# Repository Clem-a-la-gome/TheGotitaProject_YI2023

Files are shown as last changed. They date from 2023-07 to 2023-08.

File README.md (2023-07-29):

# The Gotita Project - Young Innovators 2023

This repository has been made in the context of the Young Innovator scholarship of 2023 granted by the Colombian Ministry of Science. Our ambition is to create a water quality monitoring system for rural isolated zones.

<p align="center">
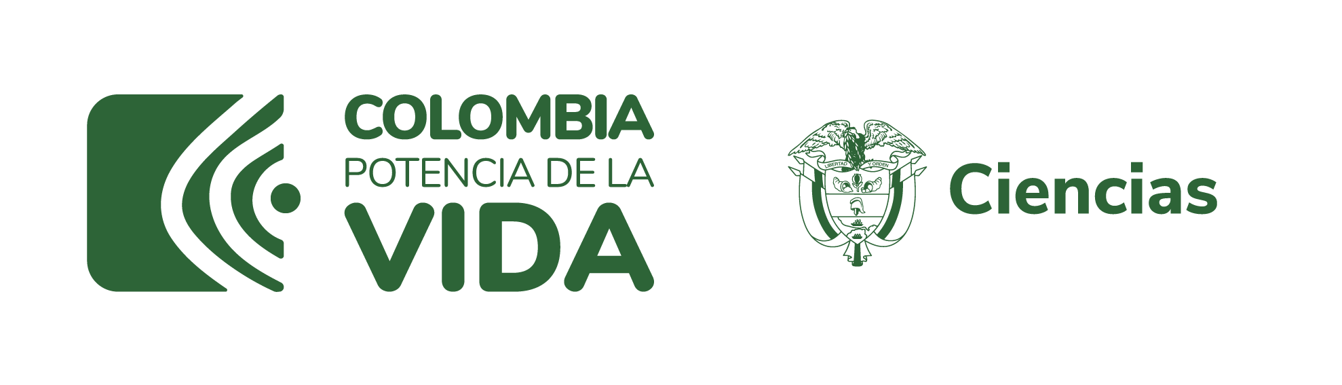
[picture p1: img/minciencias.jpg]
  
</p>

## Problem Statement

In 2017, an estimated 1.2 million people died due to unsafe water sources. This was 2.2% of global deaths. More particularly, In Colombia, there is a severe problem with access to drinking water in rural areas, where the supply doesn't exceed 35%. In addition, in 2020 approximately 884,545 cases of Acute Diarrheal Disease (ADD) were estimated. This disease is highly related to the consumption of water of poor quality.

<p align="center">
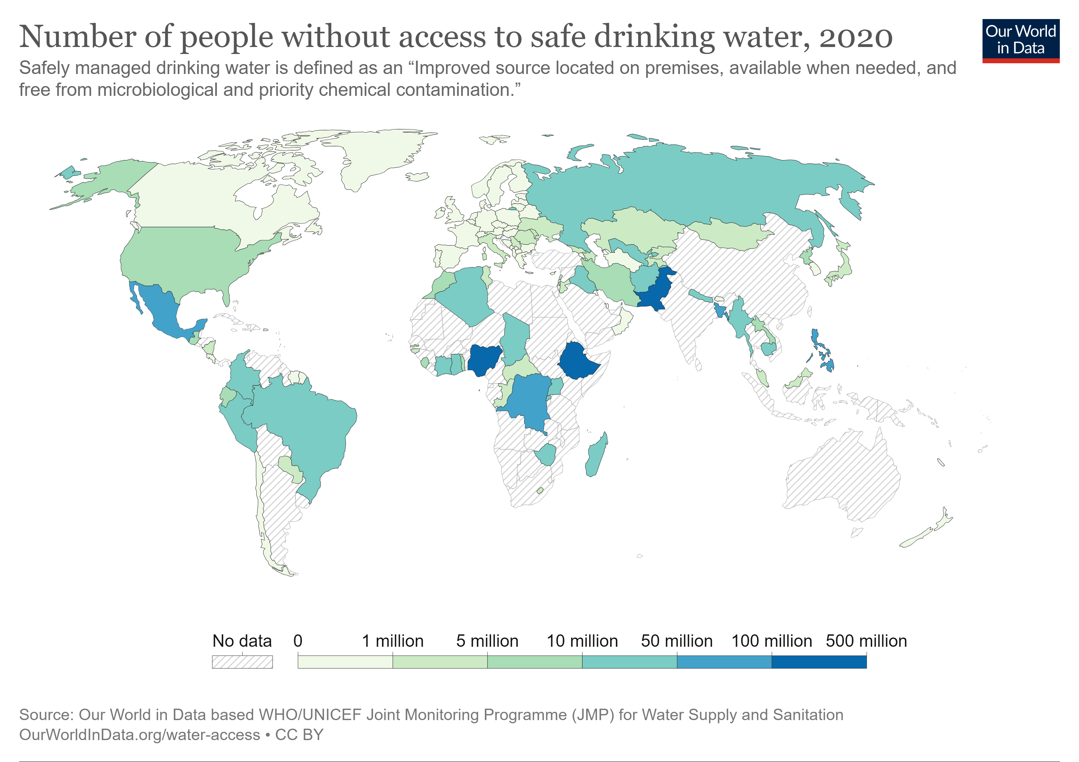
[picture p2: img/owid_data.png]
  
</p>

Ensuring good water quality is a huge challenge for public utility companies, governments, and NGOs. Nowadays, in rural areas, water quality is being measured with manual techniques, and samples need to be transported to laboratories that are very far away from these places. In fact, more than 35% of water samples wouldn't reach laboratories on time to be correctly analyzed.

## Proposal for the young innovator scholarship of 2023

The Gotita Project it's a system that can measure water quality variables and send them to the cloud through the LoRaWAN protocol. To collect the data, we will use environmental electronic sensors. This system will be connected to a web app to visualize the data. 

**Measured variables:**
- Ph
- Temperature
- Water Level
- Turbidity
- Conductivity
- Dissolved Oxygen

## Index
1. [CAD](./cad)
2. [Microcontrollers](./microcontrollers)
3. [Web App](.webapp)

<p align="center">
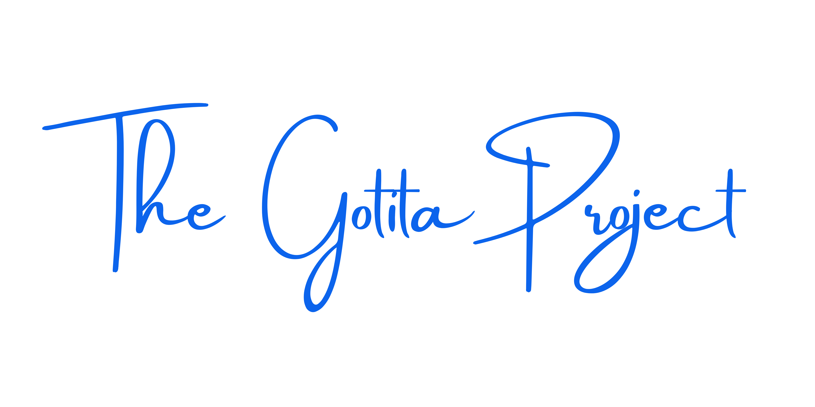
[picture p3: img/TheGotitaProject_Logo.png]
  
</p>

## License 

This repository is under [MIT License](./LICENSE.md).

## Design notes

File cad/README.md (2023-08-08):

# Designing of the system

## First Version of TGP

The first version of the TGP has been designed with PVC components that can be found commercially in shops specialized in construction. There also some
components that have been designed for 3D printing and laser manufacturing of acrylic. 

Some weaknesses have been detected in this first version. First of all, the use screws and brackets to attach the T tube and the box isn't optimal. We also 
have detected a risk with insects, particularly with ants. Future versions need to improve the sealing of electronic components to prevent damage that can 
be related to insects.

<p align="center">
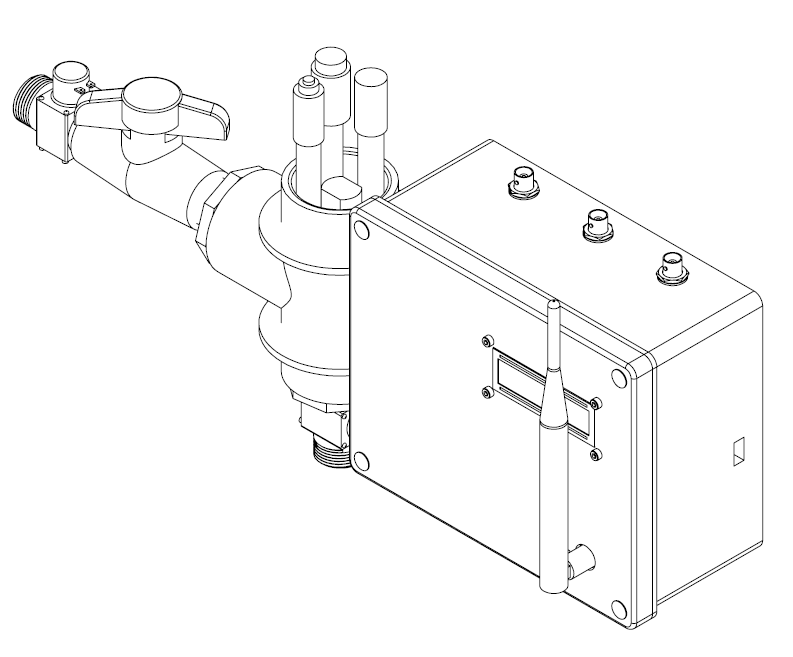
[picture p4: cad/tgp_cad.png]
  
</p>

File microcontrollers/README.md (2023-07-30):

# Microcontrollers

In this directory you will find: 

- The circuits for the node.
- Code sample to configure the Pygate
- Code to configure the Fipy/Lopy or the Arduino.

## [Arduino](./arduino)

If you want to learn and test the sensors before using them on Pycom boards, we have added the code to use these sensors on the Arduino. You can also find the associated circuit where all the connections are shown. Since their input pins can support the 5V sent by the sensors, a voltage divider is not needed.

<p align="center">
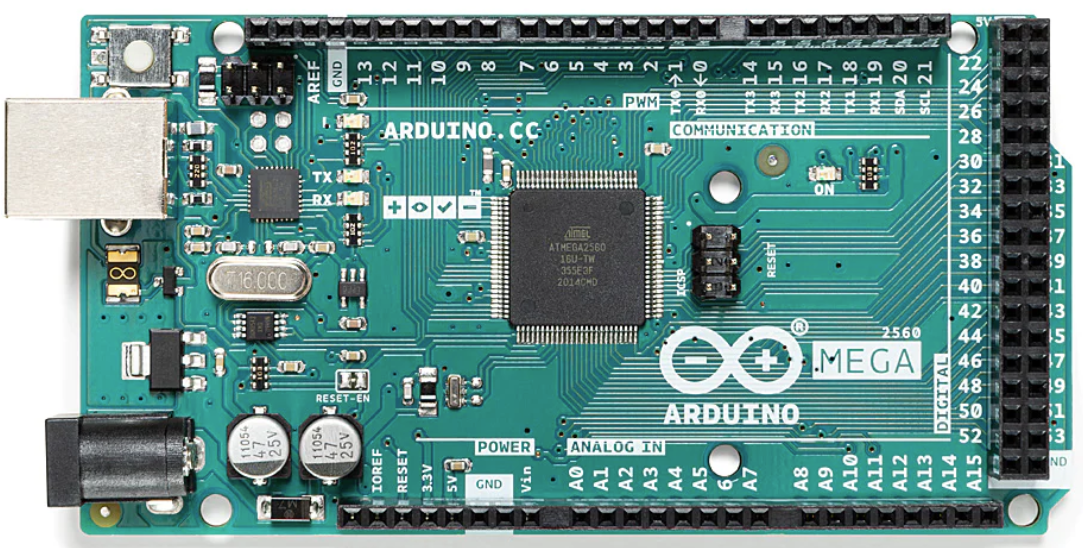
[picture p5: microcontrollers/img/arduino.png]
  
</p>

## [Pycom](./pycom)

Pycom microcontrollers are used specifically for IoT purposes and can work with multiple radio frequencies (RF). These microcontrollers are based on the ESP32 and Micropython is their coding language. 

In this project, we explored the LoRa RF and the LoRaWAN protocol. The LoRaWAN protocol consists of a Gateway that receives messages that are sent by the nodes through LoRa RF and uploads them to the cloud through an Ethernet protocol or WiFi.

<p align="center">
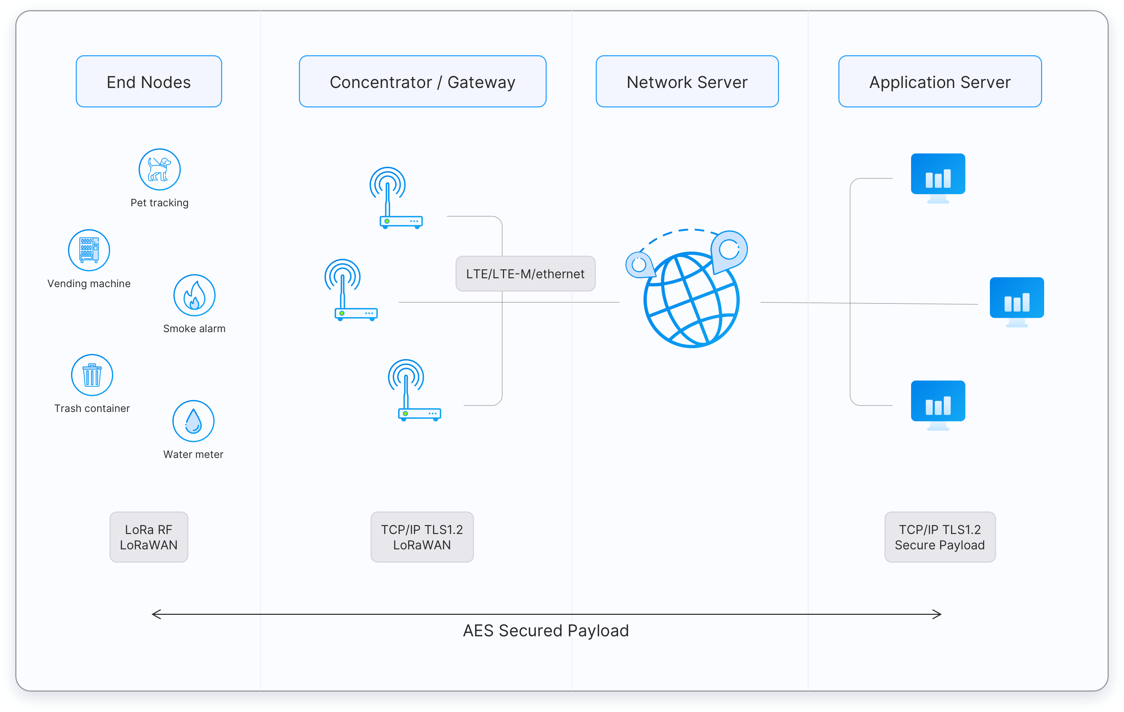
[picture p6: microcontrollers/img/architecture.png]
  
</p>

### [Gateway - Pygate](./pycom/pygate)

The Pygate is the Pycom shield that aloud us to configure the microcontrollers as gateways for the LoRaWAN protocol. They will be the gate between the messages sent from the node and The Things Network (TTN). TTN it's a server that can manage our devices connected by LoRaWAN protocol. Their role is to receive the payload (corresponding to the message in bits), traduce them into real data, and then sent it to the app through HTTP integration for example.

<p align="center">
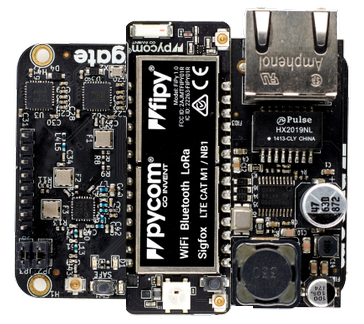
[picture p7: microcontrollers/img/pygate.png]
  
</p>

### [Node configuration - FiPy + Expansion board](./pycom/tgp_program)

We have used a FiPy and the 3V Expansion Board to connect the sensors and the rest of the devices. This microcontroller will send measurements firstly to the Pygate through LoRA RF in a payload given in bits, and then, the Pygate will traduce it and upload it to the cloud managed by TTN.

<p align="center">
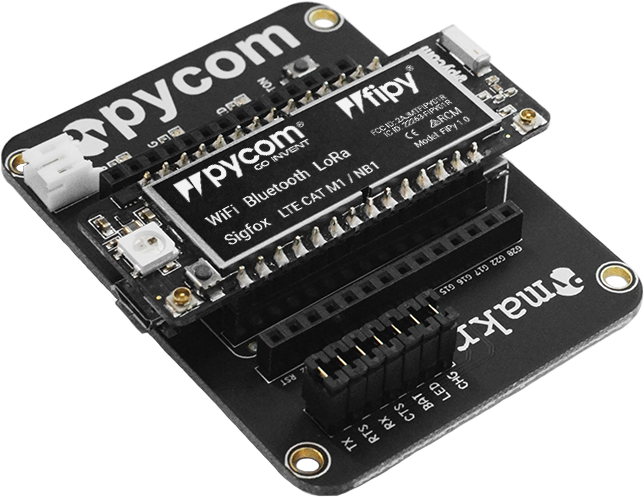
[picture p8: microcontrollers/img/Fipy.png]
  
</p>

### [Node configuration Wipy + Expansion board [Extra: MQTT protocol]](./pycom/mqtt)

We have added another example using MQTT protocol and Wipy (This can also be used with the Lopy or Fipy, just don't disconnect the LoRa antenna as this can damage the devices).

<p align="center">
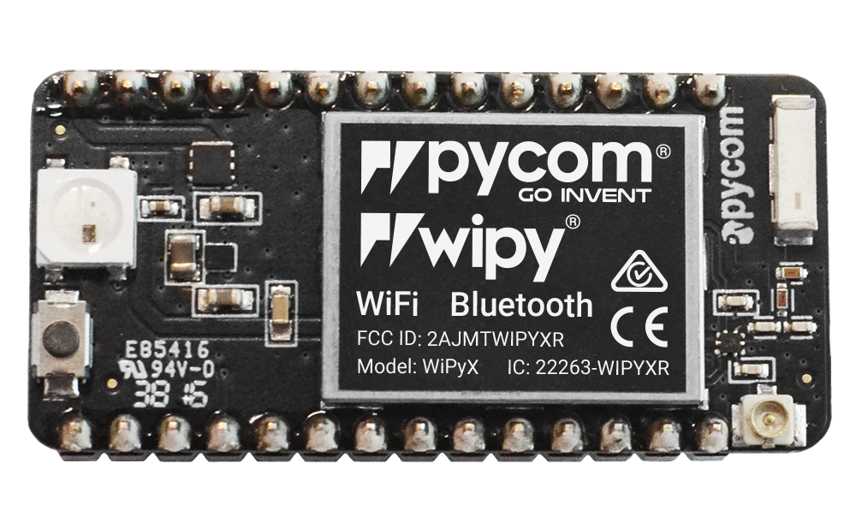
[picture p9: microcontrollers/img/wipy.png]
  
</p>

## License 

This repository is under [MIT License](https://github.com/clem-gh/TheGotitaProject_YI2023/blob/main/LICENSE.md).

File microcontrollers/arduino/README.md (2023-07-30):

 # Circuit

# Arduino Mega 2560

If you want to check the pinout diagram of the LoPy4, you can check it [here](https://content.arduino.cc/assets/Pinout-Mega2560rev3_latest.pdf).

<p align="center">
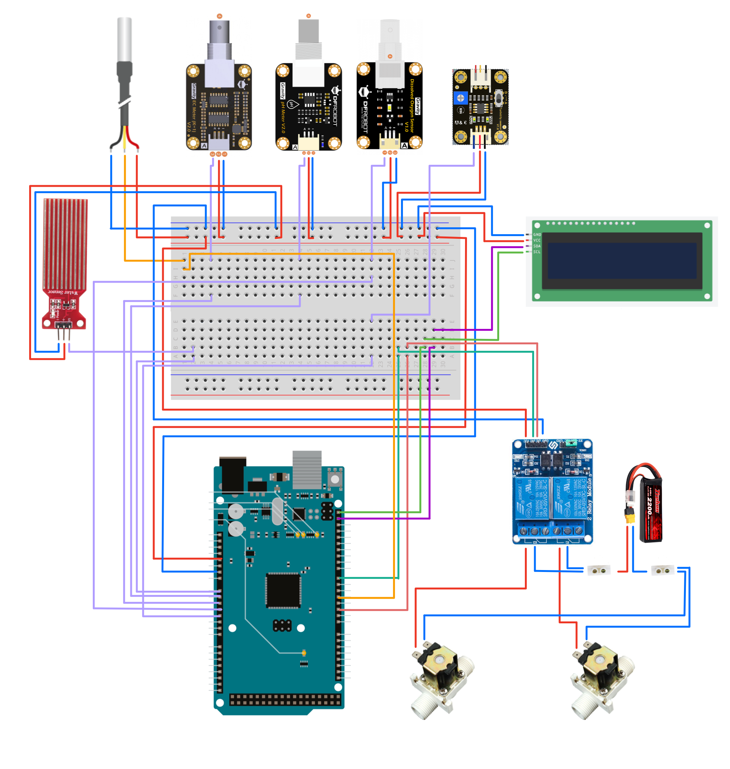
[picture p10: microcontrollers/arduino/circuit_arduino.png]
  
</p>

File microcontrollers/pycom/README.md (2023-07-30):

# Circuits

The circuits used for TGP have been added below. There is an important difference between the LoPy4 and the Fipy because both devices have different functionalities
in some of their pins. For this reason, the Lopy can have more sensors than the Fipy, because some of the pins in the Fipy are used for LTE communication. 

## Circuit using Lopy

If you want to check the pinout diagram of the LoPy4, you can check it [here](https://docs.pycom.io/gitbook/assets/lopy4-pinout.pdf).

<p align="center">
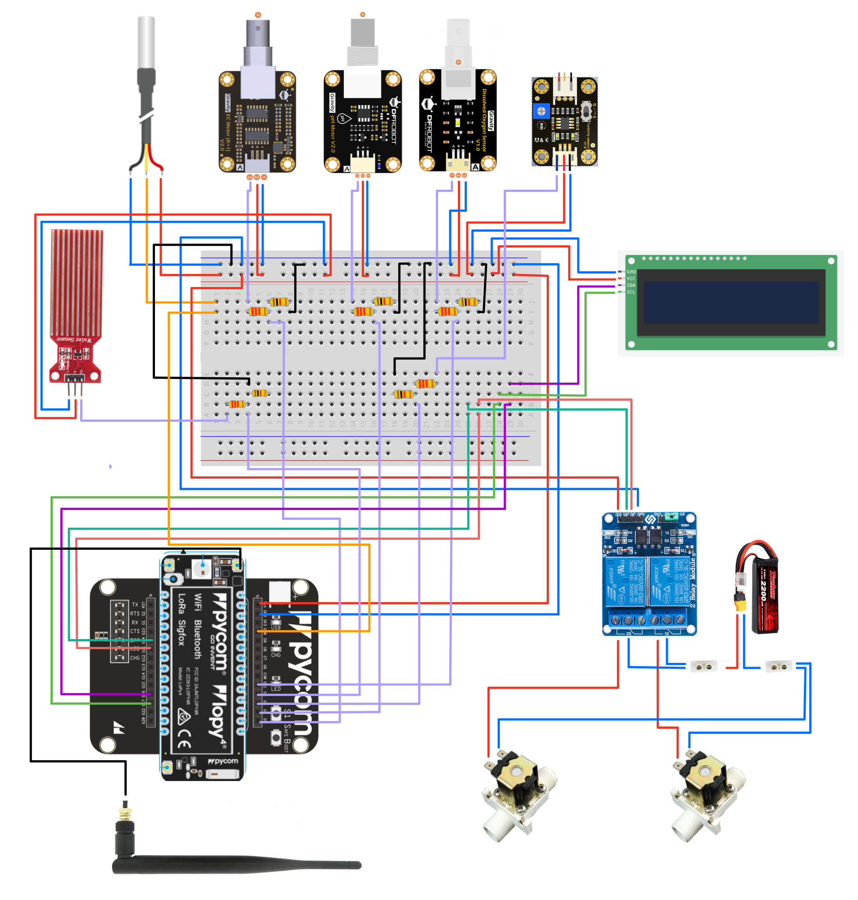
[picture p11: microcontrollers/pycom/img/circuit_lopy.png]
  
</p>

## Circuito using Fipy

If you want to check the pinout diagram of the FiPy, you can check it [here](https://docs.pycom.io/gitbook/assets/fipy-pinout.pdf).

<p align="center">
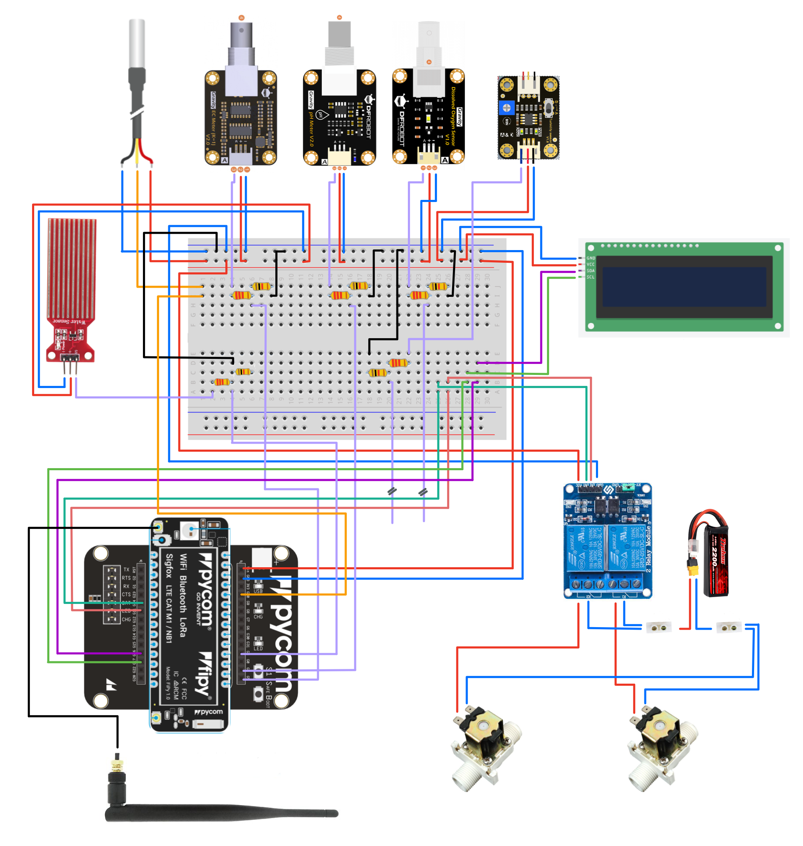
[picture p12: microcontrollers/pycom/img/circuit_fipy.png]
  
</p>

## Circuit using Wipy3

If you want to check the pinout diagram of the WiPy3, you can check it [here](https://docs.pycom.io/gitbook/assets/wipy3-pinout.pdf).

<p align="center">
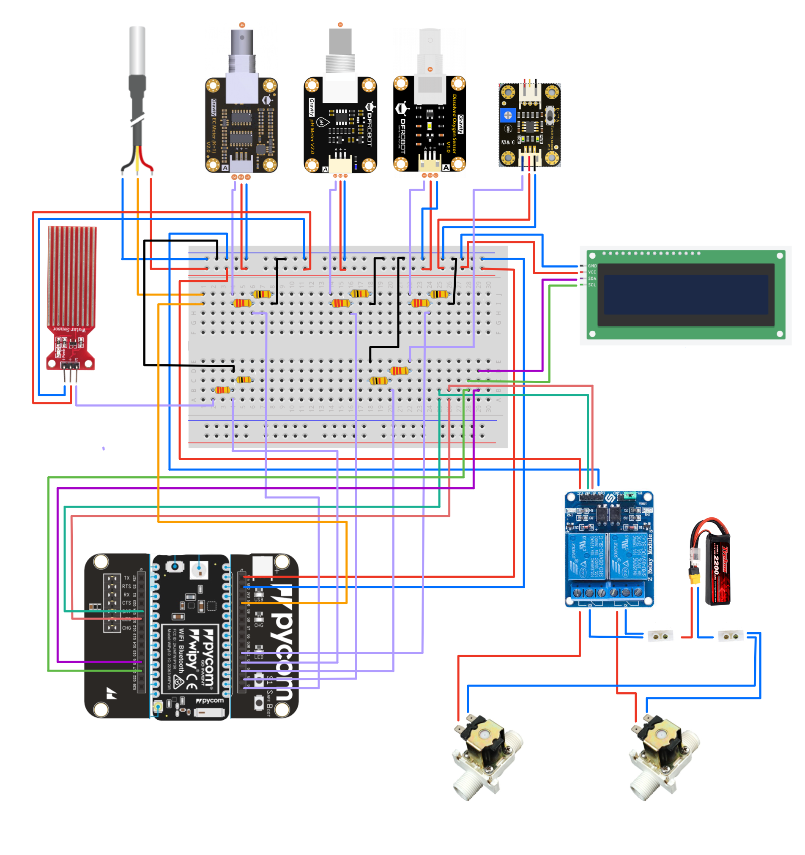
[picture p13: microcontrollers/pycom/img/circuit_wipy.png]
  
</p>

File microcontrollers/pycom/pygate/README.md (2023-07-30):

# The pygate

These are the steps to configure your Pygate: 

## 1. Updating the firmware on the PyGate expansion board

You need to upload the firmware manually to this specific expansion board. A complete video on this topic can be found 
[here](https://www.youtube.com/watch?v=FkycTZvj-ss&t=615s&ab_channel=CoreElectronics).

You also have some resources concerning this topic on the Pycom official documentation [here](https://docs.pycom.io/updatefirmware/expansionboard/). There you can 
find the archives necessary for the updating of the device.

## 2. Udpating the firmware on the FiPy

The firmware of the Fipy can be uploaded manually like the PyGate, but there is another way much simpler. You just need to connect the Fipy to the Expansion board
and then use the updating software built by Pycom. This software can be found [here](https://docs.pycom.io/updatefirmware/device/), as well as the tutorial. 
If you need more information, I recommend you to check this [video](https://www.youtube.com/watch?v=TEfiMnkvyyM&t=188s&ab_channel=Pycom).

## 3. Assembling the Pygate

You need to assemble all the components:

- The shield A.K.A PyGate expansion board
- The microcontroller: it can be either a LoPy, LoPy 4 or a Fipy
- The Ethernet adapter (optional) if you want to power the PyGate by an ethernet cable - ⚠️ don't use the USB C port when using this methodology
- The LoRa antenna - ⚠️ don't power on your device if the antenna is not connected as you might damage the LoPy
- The case

## 4. Configure the code

First of all, you need to configure your Gateway. For this, you need to go to the [global_config.json](./global_config.json) and set the EUI indicated at the end of the JSON file. The EUI it's a 64 bit extended unique identifier for each gateway. There is a complete explanation [here](https://hackmd.io/@sMJAvvKqQ6OQ7Y1uLK8WYQ/S1dhsfIp_#My-own-LoRa-gateway) on how to obtain a unique EUI identifier for your gateway using your pycom device.

The last step is to configure the settings of the wifi. Change the SSID (Name) and the Password to your own wifi settings in [main.py](./main.py).

## 5. Upload the files to the PyGate

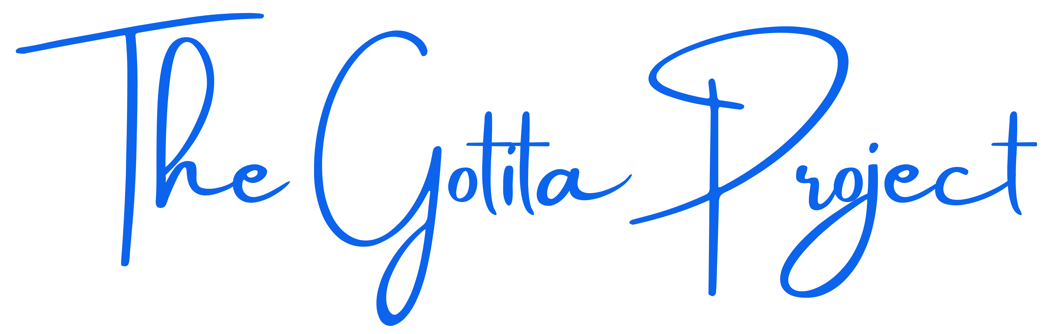
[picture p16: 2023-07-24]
webapp/src/images/name.png

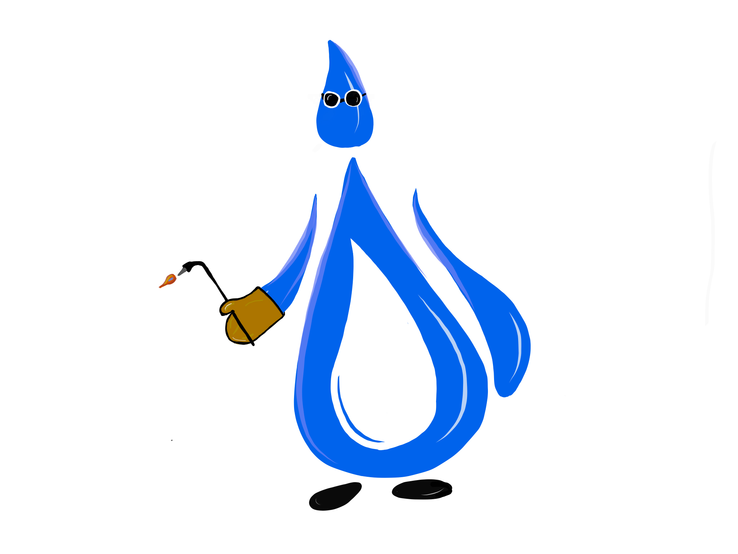
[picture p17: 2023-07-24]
webapp/src/images/tgp4.jpg

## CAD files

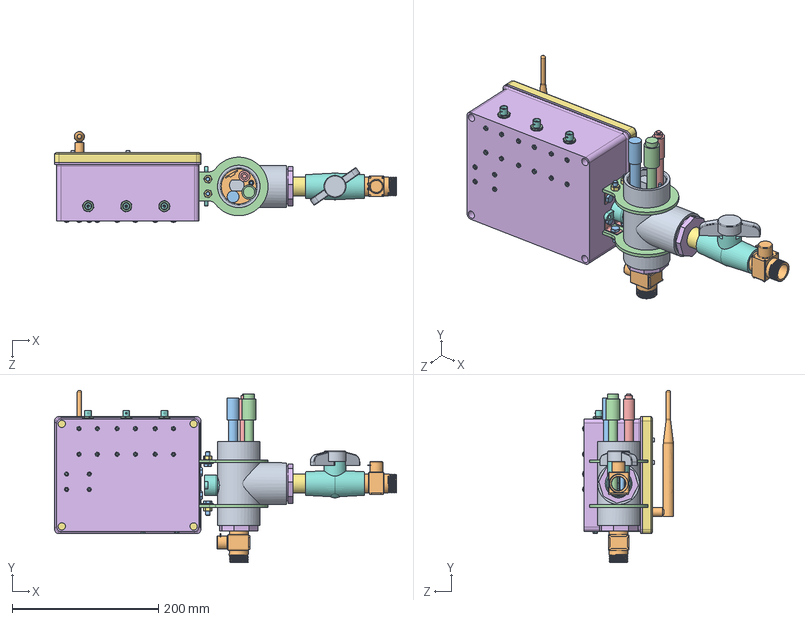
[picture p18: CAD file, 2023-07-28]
cad/CAD_1V/ensamblaje.SLDASM
467.0 x 235.2 x 124.2 mm
t_pipe
sensors_support_1 x 2
do_electrode
ec_electrode
pH_electrode
reducing_coupling x 2
funnel
turbidity_sensor
motor
level_sensor
sensors_support_2
t_supports x 2
bracket x 4
PART_ONE
PART_TWO
Gravity Dissolved Oxygen Sensor v1.0 x 3
Gravity Turbidity Sensor
Relay - 2 Channel - 2PH63091A
BreadBoard
support x 20
LCD 16X2
pycom_box
din_en_iso_4032_m6x1 x 8
din_en_iso4035_m3x0_5 x 24
din_912-m3x0_5-16-10_9 x 24
Antenna90deg
screw_din_933-m6x16-10_9-a x 8
ebttr10-0_75-2 x 3
sello x 3
Lipo_Battery_12v
niple
ball_valve_part1
ball_valve_part2
electrovalvula x 2
DS18B20.stp
reducing_ring_4mm_d26mm x 3
reducing_ring_2mm_d26mm

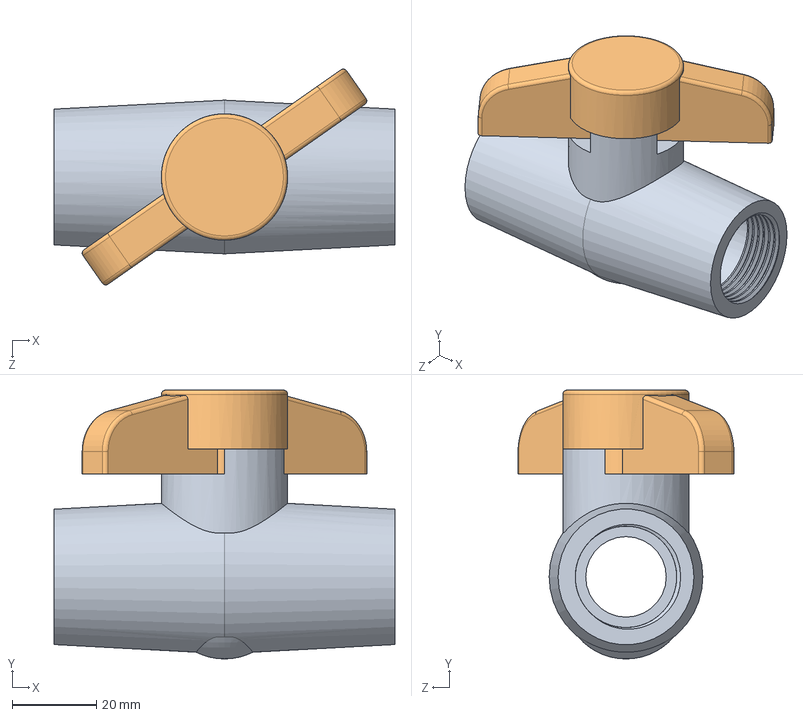
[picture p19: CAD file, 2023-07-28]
cad/CAD_1V/pipeline_connection/ball_valve.SLDASM
81.0 x 63.9 x 51.3 mm
ball_valve_part1
ball_valve_part2

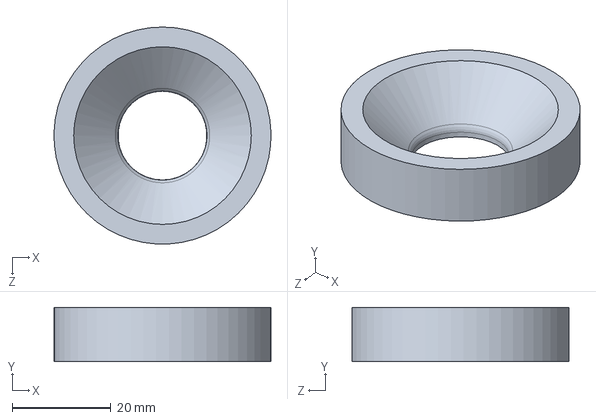
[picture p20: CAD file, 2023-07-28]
cad/CAD_1V/3D/funnel.SLDPRT
44.0 x 11.0 x 44.0 mm

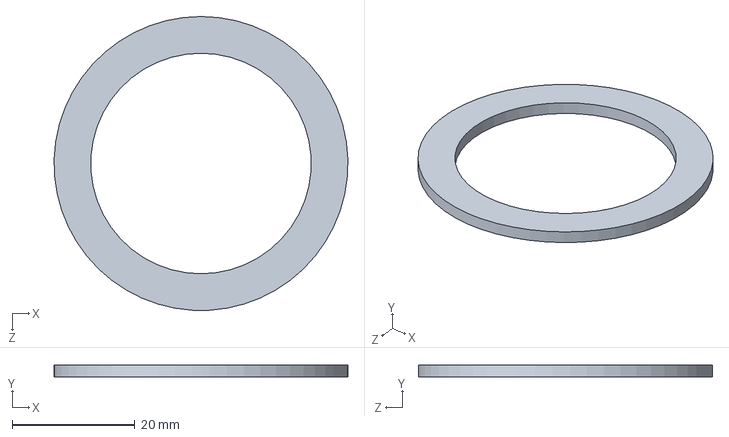
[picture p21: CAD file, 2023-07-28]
cad/CAD_1V/acrilyc/reducing_ring_2mm_d36mm.SLDPRT
48.0 x 2.00 x 48.0 mm

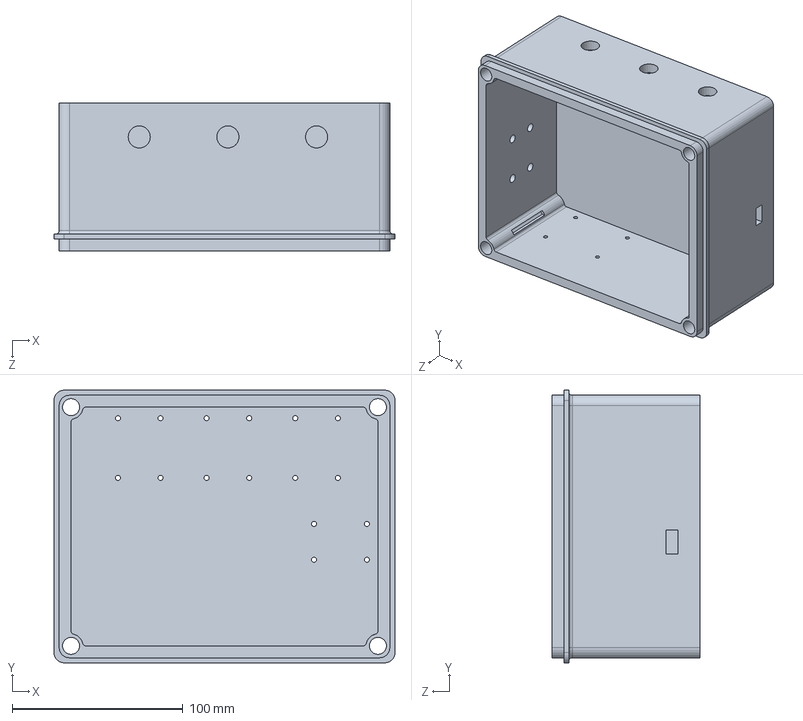
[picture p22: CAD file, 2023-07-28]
cad/CAD_1V/box/PART_ONE.SLDPRT
200.0 x 160.0 x 87.0 mm

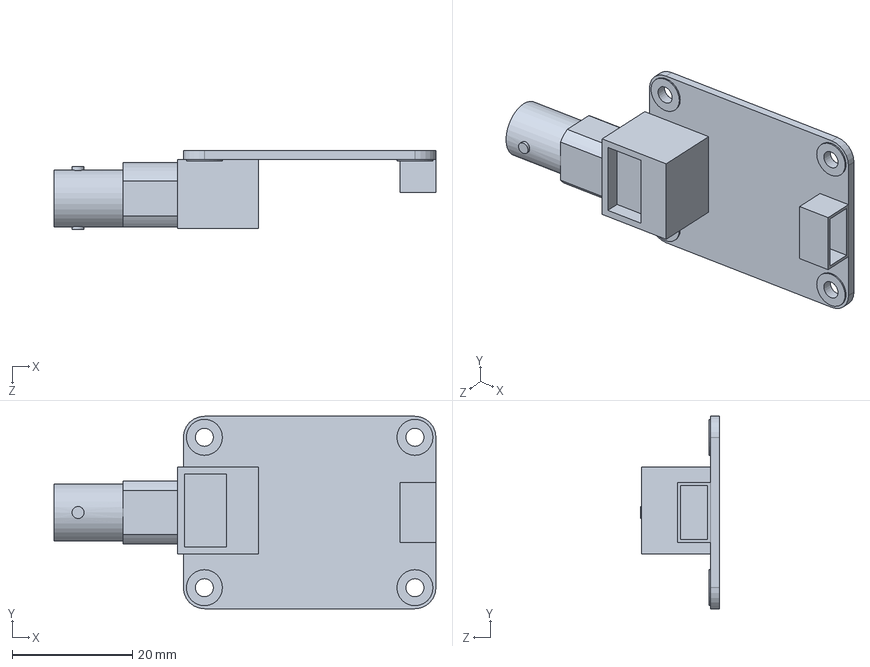
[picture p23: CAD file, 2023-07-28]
cad/CAD_1V/electronics/Gravity Dissolved Oxygen Sensor v1.0.SLDPRT
63.5 x 32.0 x 13.2 mm

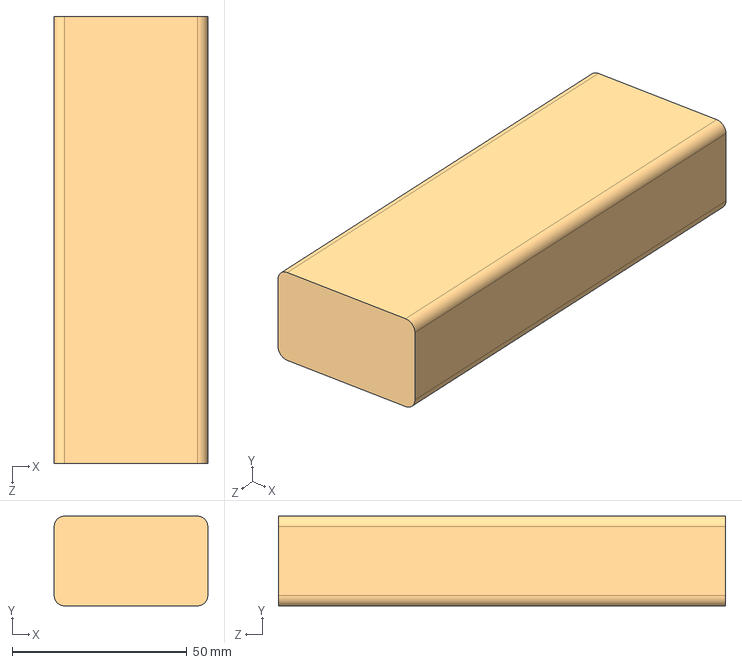
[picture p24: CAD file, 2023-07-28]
cad/CAD_1V/electronics/lipo-battery-12v/Lipo_Battery_12v_IGES.IGS
44.0 x 25.7 x 128.0 mm

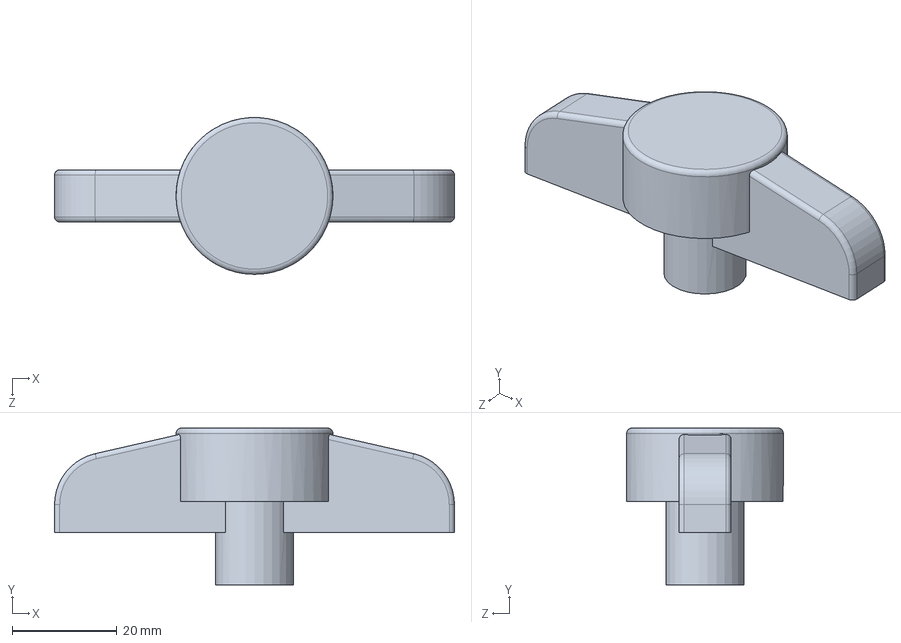
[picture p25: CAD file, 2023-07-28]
cad/CAD_1V/pipeline_connection/ball_valve_part2.SLDPRT
76.5 x 30.0 x 30.0 mm

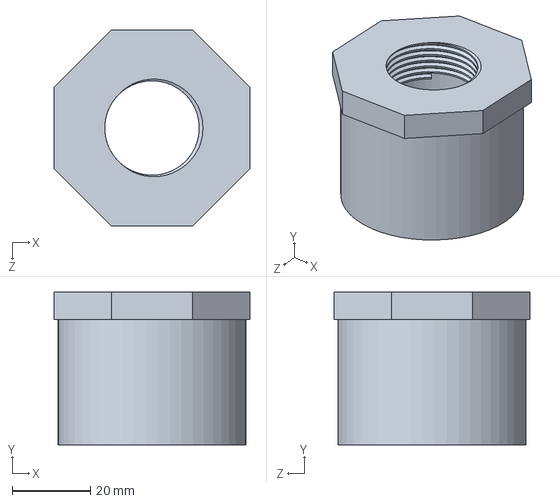
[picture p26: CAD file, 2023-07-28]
cad/CAD_1V/t_pipe/reducing_coupling.SLDPRT
50.0 x 39.0 x 50.0 mm

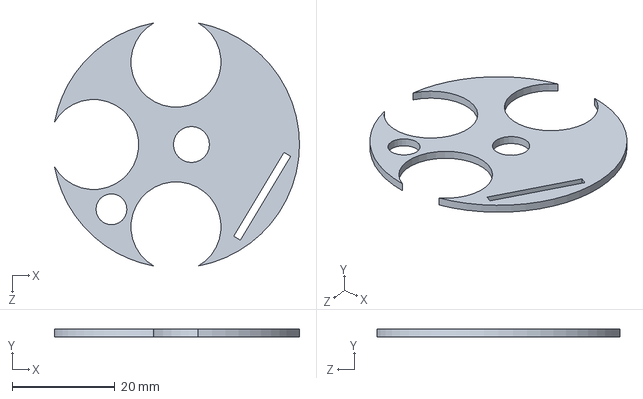
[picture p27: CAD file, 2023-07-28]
cad/CAD_1V/acrilyc/sensors_support_2.SLDPRT
47.6 x 1.50 x 47.2 mm

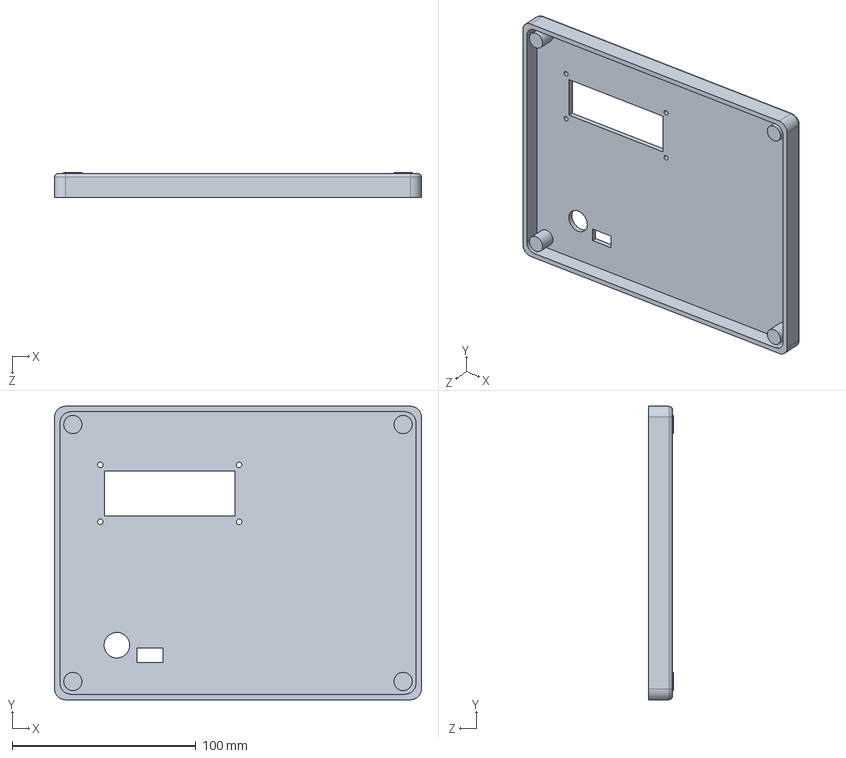
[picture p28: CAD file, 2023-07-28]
cad/CAD_1V/box/PART_TWO.SLDPRT
200.0 x 160.0 x 13.5 mm

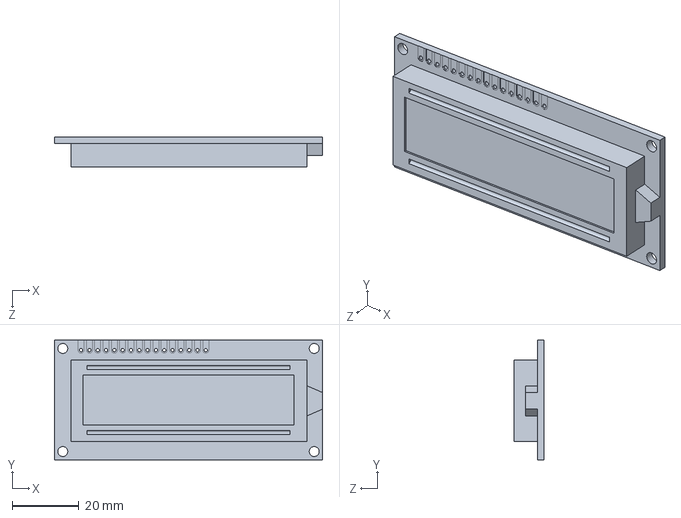
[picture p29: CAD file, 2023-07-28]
cad/CAD_1V/electronics/LCD 16X2.SLDPRT
80.6 x 36.0 x 9.00 mm

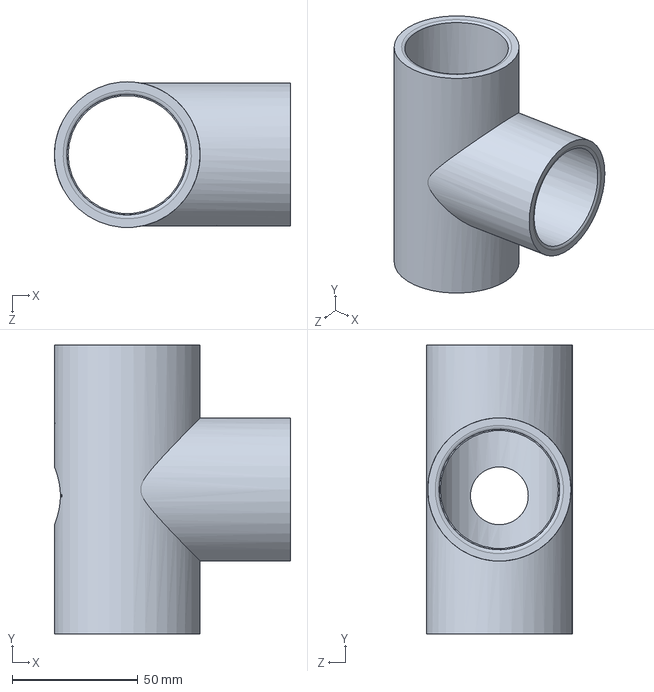
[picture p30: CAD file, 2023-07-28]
cad/CAD_1V/t_pipe/t_pipe.SLDPRT
94.0 x 115.0 x 57.9 mm

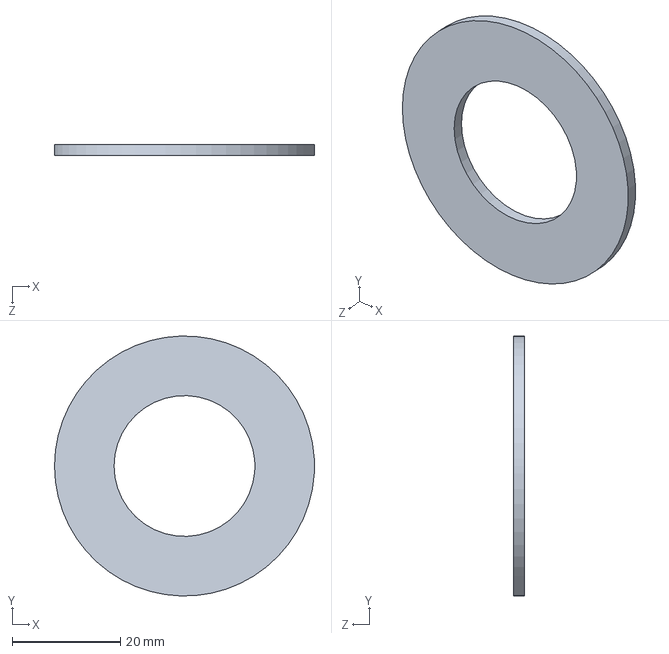
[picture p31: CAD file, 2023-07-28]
cad/CAD_1V/acrilyc/reducing_ring_2mm_d26mm.SLDPRT
48.0 x 48.0 x 2.00 mm

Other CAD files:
cad/CAD_1V/electronics/lipo-battery-12v/Lipo_Battery_12v.SLDPRT
cad/CAD_1V/electronics/lipo-battery-12v/Lipo_Battery_12v_step.STEP
cad/CAD_1V/electronics/motor.SLDPRT
cad/CAD_1V/pipeline_connection/niple.SLDPRT
cad/CAD_1V/ENSAMBLAJE.SLDDRW
cad/CAD_1V/acrilyc/reducing_ring_4mm_d26mm.SLDPRT
cad/CAD_1V/acrilyc/sensors_support_1.SLDPRT
cad/CAD_1V/acrilyc/t_supports.SLDPRT
cad/CAD_1V/electronics/Antenna90deg.SLDPRT
cad/CAD_1V/electronics/DS18B20.stp.SLDPRT
cad/CAD_1V/electronics/Gravity Turbidity Sensor.SLDPRT
cad/CAD_1V/electronics/Relay - 2 Channel - 2PH63091A.SLDPRT
cad/CAD_1V/electronics/do_electrode.SLDPRT
cad/CAD_1V/electronics/ec_electrode.SLDPRT
cad/CAD_1V/electronics/level_sensor.SLDPRT
cad/CAD_1V/electronics/pH_electrode.SLDPRT
cad/CAD_1V/electronics/pycom_box.SLDPRT
cad/CAD_1V/electronics/support.SLDPRT
cad/CAD_1V/electronics/turbidity_sensor.SLDPRT
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

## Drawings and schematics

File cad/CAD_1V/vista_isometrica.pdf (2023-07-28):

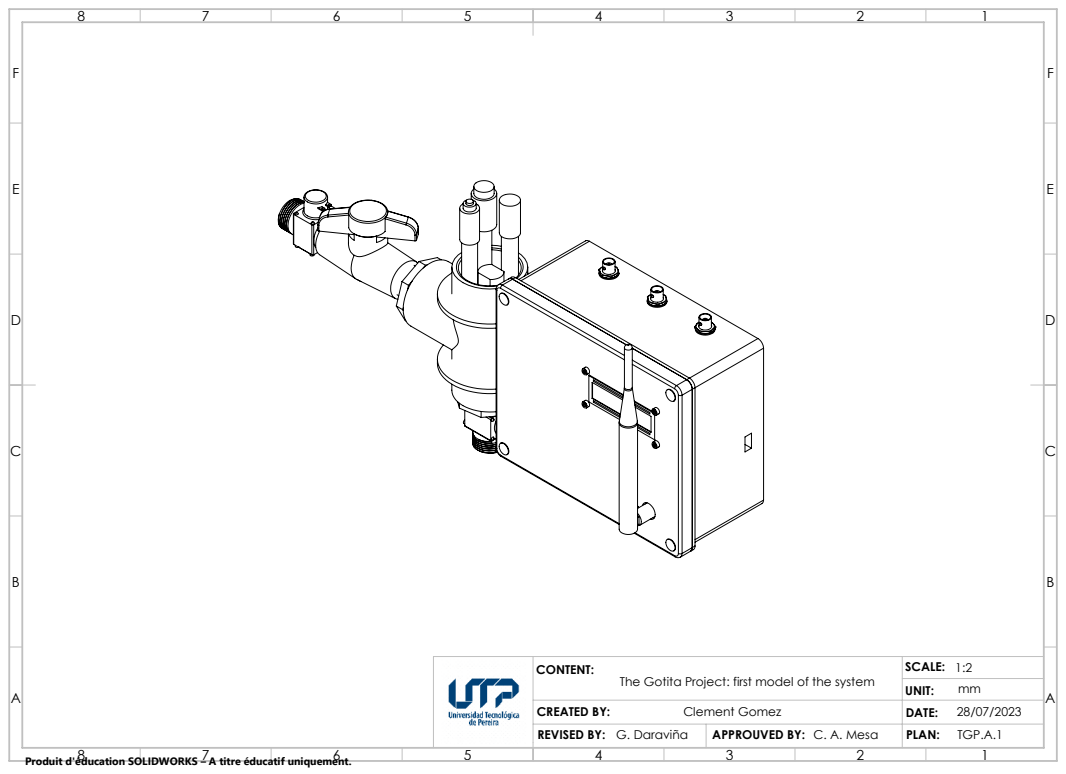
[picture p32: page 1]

The Gotita Project: first model of the system

CREATED BY: Clement Gomez | DATE: 28/07/2023
REVISED BY: G. Daraviña | APPROUVED BY: C. A. Mesa | PLAN: TGP.A.1

Produit d'éducation SOLIDWORKS – A titre éducatif uniquement.

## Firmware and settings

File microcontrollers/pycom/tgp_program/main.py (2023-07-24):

'''
    TGP software
    Author: clem-gh
    Date:   2023.7
    https://the-gotita-project-10b7c.web.app/

    =======================================

    INSTRUCTIONS
    1. Go to config.json to set the parameters of your TTN gateway.
    2. Check the RF in the lora file, if needed, change it to the one
    of your region.
    3. Connect VCC to Vin (it needs 5V).
    4. Connect sensor pins as described in the sensors.py file.

    WARNINGS
    1. Using a different RF than the one authorized in your
    region can damage your device.
    2. Don't use the 5V output from your sensors as you can damage the
    Pycom board, instead use voltage divider to reduce max V. to 3.3V.
    3. Check connections.
    4. Check LoRa Antenna connections.

'''

# Librerias estandar de pycom
import sys # Libreria para
import utime # Libreria para el uso de funciones de tiempo
import pycom # Libreria para el uso de funciones pycom
import machine # Libreria para el uso de los microcontroladores
import ubinascii #
from machine import ADC # Importe de la funcion Analog to Digital Converter
from machine import Pin, I2C # Importe de la funcion Pin para usar los pines
import ustruct
from LCD1602 import LCD1602

# Importe de archivos propios
import sensors # Contiene funcion para obtener los valores de los sensores
import lora # Contiene la funcion para conectar a LoRa y TTN
lora.connect_lora() # Conexion a LoRaWAN
# Advertencia: Primero se debe conectar a Lora antes de importar el 'socket'
from lora import s # Importa el 'socket' del archivo lora

# Configuracion de pines de automatizacion
adc = ADC(bits=10) # Objeto ADC de bits=10: rango de 0-1024
apin_L = adc.channel(attn=ADC.ATTN_11DB, pin='P16') # Sensor analogo de nivel
relay_pin_1 = Pin('P3', mode=Pin.OUT) # Pin relay superior
#Pin 11 en 0 abre rele superior, en 1 cierra rele superior
relay_pin_2 = Pin('P4', mode=Pin.OUT) # Pin relay inferior
#Pin 12 en 0 abre rele inferior, 1 cierra rele inferior

# Configuracion del LCD
sda = 'P9'
scl = 'P10'
i2c = I2C(1, pins=(sda, scl))
LCD = LCD1602(i2c)

# Estado incial del microcontrolador
state = int(0) # Establece que el estado incial es 0
tk = False #  Token estado del tiempo: True 'Tiempo en uso' False 'Tiempo en desuso'
send_value = False

pycom.heartbeat(False)

while True: # Loop infinito

    lvl=apin_L.voltage() # Calcula el diferencial del sensor de nivel

    #Estado Inicial: Valvula superior abierta, valvula inferior cerrada
    relay_pin_1.value(0) # Relay superior abierto
    relay_pin_2.value(1) # Relay inferior cerrado

    current_time = utime.ticks_ms()

    if state == 0:
        if lvl <= 1500:
            # Etaba 1 (Inicial): Entra agua al sistema
            relay_pin_1.value(0) # Relay superior abierto
            relay_pin_2.value(1) # Relay inferior cerrado
            LCD.puts("Flujo entra...")
            print("Flujo entrando...")
        else:
            #Etapa 2: Se cierra la valvula y se miden variables durante 10s
            relay_pin_1. value(1) # Relay inferior cerrado
            print("Nivel de agua alcanzado... Cierre de valvula superior")
            LCD.puts("Nivel alcanzado")
            if send_value == False:
                for i in range(5): # Toma la quinta medicion
                    #ec, ph, do, temp, turb = sensors.values()
                    ec, ph, temp = sensors.values()
                    ec = ec*100
                    ph = ph*10
                    temp = temp*10
                    print("EC: %d" %(ec*100))
                    print("pH: %d" %(ph*100))
                    print("T: %d" %(temp*10))
                    if i == 4:
                        send_value = True
            else:
                #/---------/ Se envian valores a TTN /-------------/

                #package = ustruck.pack('>h',int(ec)) + ustruct.pack('>h',int(ph)) + ustruct.pack('>h',int(do)) + ustruct.pack('>h',int(temp)) + ustruct.pack('>h',int(turb))
                package = ustruct.pack('>h', int(temp)) +  ustruct.pack('>h', int(ec)) +  ustruct.pack('>h', int(ph))
                s.send(package)
                print("Paquete de carga enviado: T %d" %(temp))
                print("Paquete de carga enviado: EC %d" %(ec))
                print("Paquete de carga enviado: pH %d" %(ph))

                LCD.puts("Paquete enviado")
                print("Mediciones terminadas...")
                state = int(1) # Indica el siguiente estado del programa
                tk = False # No se puede usar el cronometro de la etapa 2
                send_value = False

    elif state == 1:
        # Etapa 3: El agua se evacua durante 10s.
        print("Evacuacion del agua... Apertura de la valvula inferior")
        LCD.puts("Evacua agua")
        relay_pin_2.value(0) # Relay inferior abierto
        relay_pin_1.value(1) # Relay superior cerrado
        if tk == False:
            start_time = current_time # Guarda el instante que la etapa 3 comenzo
            tk = True # Se puede usar el cronometro de la etapa 3
            print("Comienza Cronometro")
        else:
            time_elapsed=utime.ticks_diff(current_time, start_time) # Hace funcion de cronometro
            print("Cronometro: %d ms... Evacuando Agua." %(time_elapsed))
            if time_elapsed >= 10000: # Se pasa a la siguiente etapa despues de 10s
                state = 2 # Indica el siguiente estado del programa
                tk = False # No se puede usar el cronometro de la etapa 3
                print("Sistema vacio...")
    else:
        # Etapa 4: El dispositivo queda en reposo por 15 min
        print("Dispositivo en reposo durante 30s...")
        LCD.backlight(0)
        LCD.clear()
        state = 0 # El estado vuelve al incial
        relay_pin_2.value(1) # Relay inferior cerrado
        relay_pin_1.value(1) # Relay superior cerrado
        utime.sleep(30) # Dispositivo queda en reposo por ... s

    utime.sleep(1) # Las operaciones se repiten cada segundo

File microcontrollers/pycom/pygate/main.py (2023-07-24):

from network import WLAN
import time
import machine
from machine import RTC
import pycom

print('\nStarting LoRaWAN concentrator')
# Disable Hearbeat
pycom.heartbeat(False)

# Define callback function for Pygate events
def machine_cb (arg):
    evt = machine.events()
    if (evt & machine.PYGATE_START_EVT):
        # Green
        pycom.rgbled(0x103300)
    elif (evt & machine.PYGATE_ERROR_EVT):
        # Red
        pycom.rgbled(0x331000)
    elif (evt & machine.PYGATE_STOP_EVT):
        # RGB off
        pycom.rgbled(0x000000)

# register callback function
machine.callback(trigger = (machine.PYGATE_START_EVT | machine.PYGATE_STOP_EVT | machine.PYGATE_ERROR_EVT), handler=machine_cb)

print('Connecting to WiFi...',  end='')
# Connect to a Wifi Network
wlan = WLAN(mode=WLAN.STA)
SSID_NAME = '' #Nombre del SSID - WiFi
PASSW = '' # Contraseña para acceder a WiFI
wlan.connect(ssid=SSID_NAME, auth=(WLAN.WPA2, PASSW ))

while not wlan.isconnected():
    print('.', end='')
    time.sleep(1)
print(" OK")

# Sync time via NTP server for GW timestamps on Events
print('Syncing RTC via ntp...', end='')
rtc = RTC()
rtc.ntp_sync(server="pool.ntp.org")

while not rtc.synced():
    print('.', end='')
    time.sleep(.5)
print(" OK\n")

# Read the GW config file from Filesystem
with open('/flash/global_config.json','r') as fp:
    buf = fp.read()

# Start the Pygate
machine.pygate_init(buf)
# disable degub messages
# machine.pygate_debug_level(1)

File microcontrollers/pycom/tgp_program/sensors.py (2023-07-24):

# Librerias estandar de pycom
import pycom
import utime
import machine
from machine import ADC
from machine import Pin

# Librerias proporcionadas por los fabricantes
from DFRobot_PH import DFRobot_PH
from DFRobot_EC import DFRobot_EC
from DFRobot_DO import DFRobot_DO
from onewire import DS18X20
from onewire import OneWire

# create an ADC object bits=10 means range 0-1024
adc = ADC(bits=10)

# Llamando Librerias de los fabricantes
dfr_ph = DFRobot_PH()
dfr_ec = DFRobot_EC()


#Pines conectados a sensores
ow = OneWire(Pin('P23')) # Pin sensor DS18B20
# create an ADC object bits=10 means range 0-1024
adc = ADC(bits=10)
# apin_DO = adc.channel(attn=ADC.ATTN_11DB, pin='P17') # Pin sensor DO, solo disponibles con LoPy4
# apin_T = adc.channel(attn=ADC.ATTN_11DB, pin='P15') # Pin sensor Turbidez, solo disponibles con LoPy4
apin_EC = adc.channel(attn=ADC.ATTN_11DB, pin='P14') # Pin sensor EC
apin_PH = adc.channel(attn=ADC.ATTN_11DB, pin='P13') # Pin sensor PH

temp_v = DS18X20(ow)
dfr_ec.begin()
dfr_ph.begin()

def values():

    #Calculo de temperatura a partir de libreria
    temp = temp_v.read_temp_async()
    temp_v.start_conversion()
    if temp == None:
        temp = 25
    utime.sleep(1)

    # Lee los voltajes de entrada de los sensores
    volt_PH = apin_PH.voltage()*3.2/2.2 # Voltaje de pH
    volt_EC = apin_EC.voltage()*3.2/2.2  # Voltaje de EC
    # volt_T = apin_T.voltage() # Voltaje de turbidez
    # volt_DO = apin_DO.voltage() # Voltaje de oxigeno disuelto

    #Calcula valor de variables con voltaje de entrada a partir de librerias
    ec = dfr_ec.readEC(volt_EC,temp) # Valor de ec
    ph = dfr_ph.read_PH(volt_PH,temp) # Valor de ph
    # do = do.readDO(volt_DO,temp_read) # Valor de oxigeno disuelto

    #Calculo de Turbidez con voltaje
    # turb = -1120.4*square(volt_T)+5742.3*t_v-4353.8

    return(ec, ph, temp)

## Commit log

2023-01-16 sensor test with arduino
2023-07-24 adding new files: pycom, arduino and wa codes
2023-07-24 Update sensors.py (#3)
2023-07-30 adding arduino circuit
